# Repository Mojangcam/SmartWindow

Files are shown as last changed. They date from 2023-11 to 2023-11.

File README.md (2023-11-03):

# SmartWindow

## 사용법

* 전용 앱을 다운받아 실행 시킵니다.
* 실행을 시키면 자동으로 스마트윈도우와 연결이 됩니다.
* 왼쪽 상단에는 수동/자동 모드를 변경 할수 있는 스위치가 존재합니다.
* 오른쪽 상단에는 음성인식으로 창문을 제어할수 있게 마이크 아이콘이 존재합니다.
* 실시간으로 현재의 온도와 습도, 미세먼지의 값을 받아옵니다.
* 블루투스 연결이 자동으로 되지 않는다면 아래에 블루투스 연결 버튼을 누르면 자동으로 연결이 됩니다.
* 만약 블루투스 연결을 끊고 싶다면 바로 옆에 있는 블루투스 연결 해제 버튼을 누르면 연결이 해제 됩니다.
* 맨 아래에는 열기, 중간, 닫기의 버튼이 존재합니다.
* 열기의 버튼을 누르면 수동모드로 바뀌면서 창문이 열립니다.
* 닫기와 중간의 버튼도 누르면 수동모드로 전환되며 창문이 반만 열리거나 닫히게 됩니다.
* 앱의 사용법은 여기서 끝 입니다.

## 구성요소

### 재료

1. 미세먼지 센서
2. 온, 습도 센서
3. LCD
4. 블루투스 모듈
5. 모터 드라이버 모듈
6. DC 기어 모터
7. 브레드보드
8. 아두이노 우노
9. 리밋 스위치 2개
10. 3D프린팅한 창문

### 동작
1. 미세먼지와 온, 습도 값을 받아와 LCD에 표시해줍니다.
2. 미세먼지가 높으면 창문이 닫힙니다.
3. 미세먼지가 조금 높으면 창문이 반만 닫히거나 반만 열립니다.
4. 온도가 높아지면 창문이 열립니다.
5. 습도가 높아지면 창문이 닫힙니다.
6. 창문이 열리고 닫히는 우선순위는 닫힘 -> 반만 닫힘 -> 열림 순 입니다.

## 회로도 - 부품명 포함

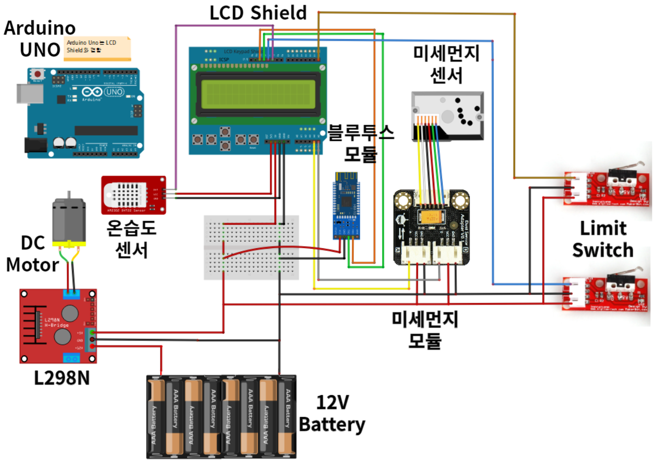
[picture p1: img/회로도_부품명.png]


## 회로도 - 부품명 미포함

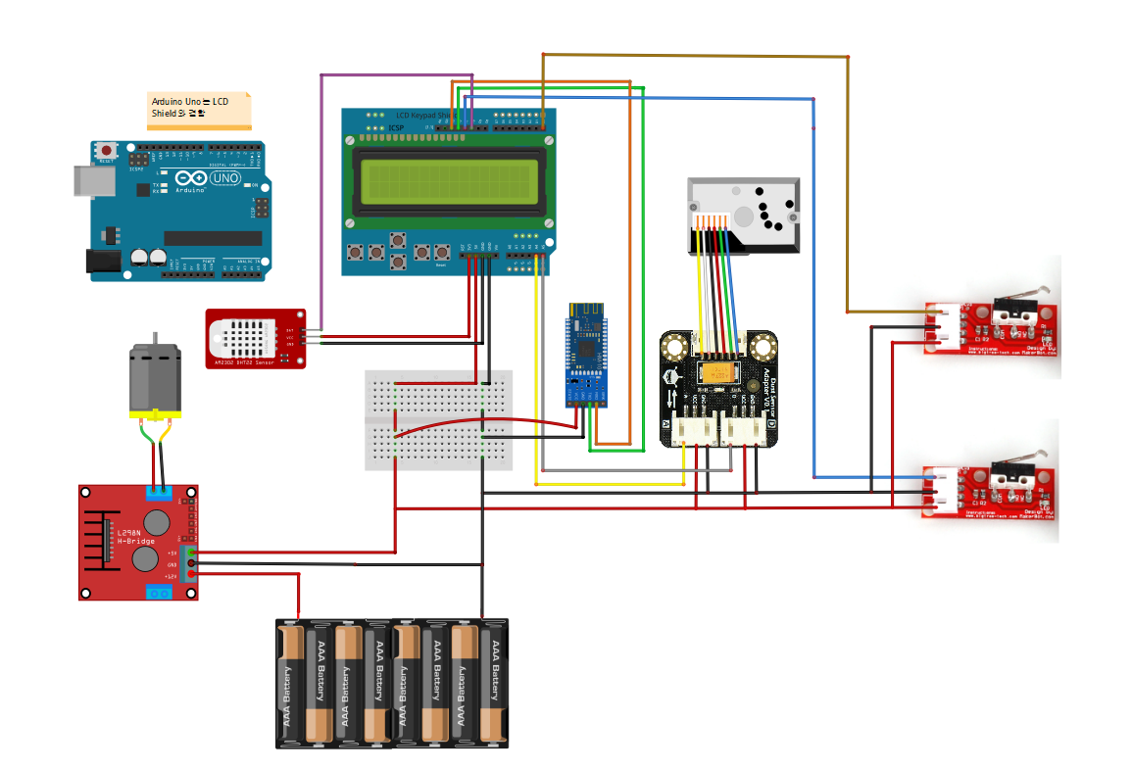
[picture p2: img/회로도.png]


## 만든 사람

### 3D 모델링 : 김수정, 조세형

### 회로 구성 : 이제현, 박상영

### 코딩 : 노종환
[동작 시연 영상 - 앱 업데이트 전](https://www.youtube.com/watch?v=2f4ua8sfkGE)

[Operation demonstration video - Before app update](https://www.youtube.com/watch?v=2f4ua8sfkGE)

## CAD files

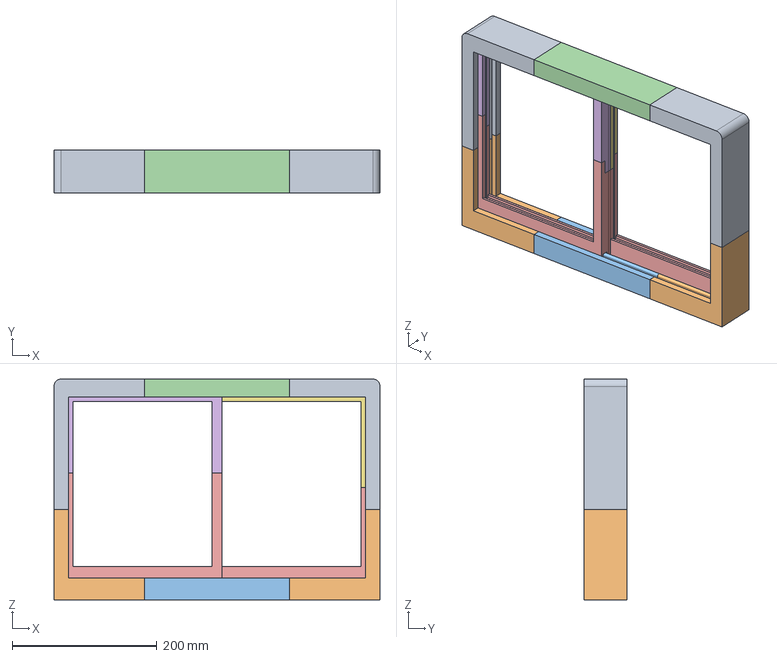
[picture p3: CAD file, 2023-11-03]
3D_Model/미니윈도.step
450.0 x 60.0 x 305.0 mm

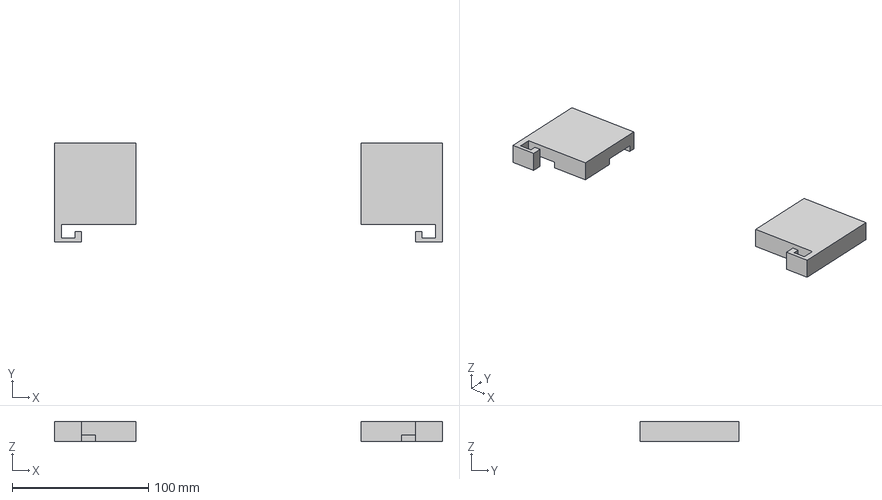
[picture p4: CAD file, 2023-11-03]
3D_Model/받침대.step
285.0 x 73.0 x 15.0 mm

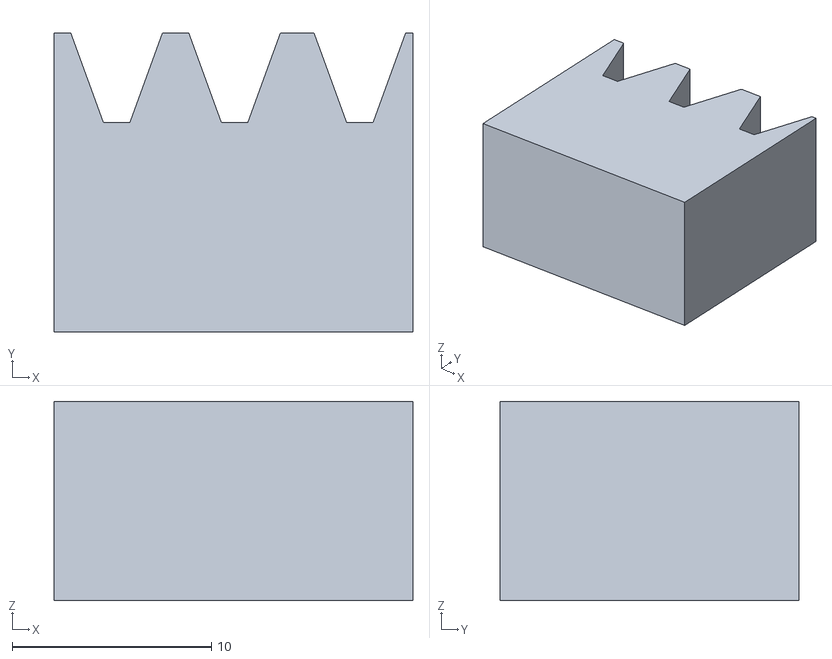
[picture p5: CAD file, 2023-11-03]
3D_Model/래크기어.stl
18.0 x 15.0 x 10.0

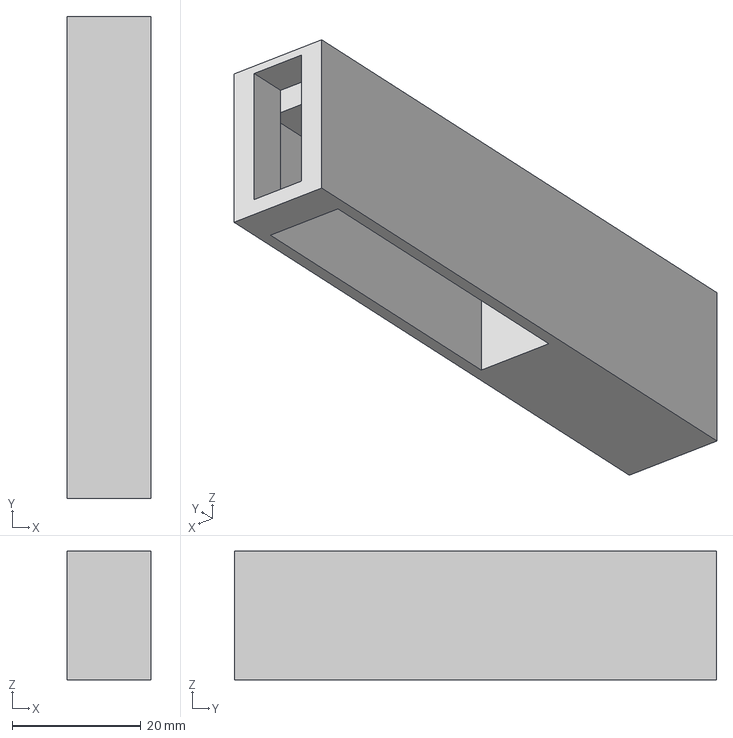
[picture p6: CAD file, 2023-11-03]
3D_Model/스위치 홈.step
13.0 x 75.0 x 20.0 mm

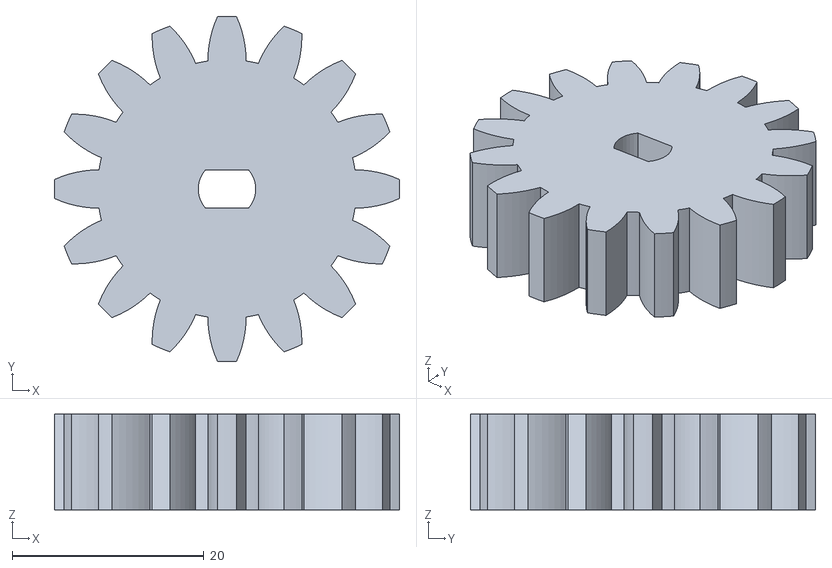
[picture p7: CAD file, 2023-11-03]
3D_Model/피니언기어.stl
36.0 x 36.0 x 10.0

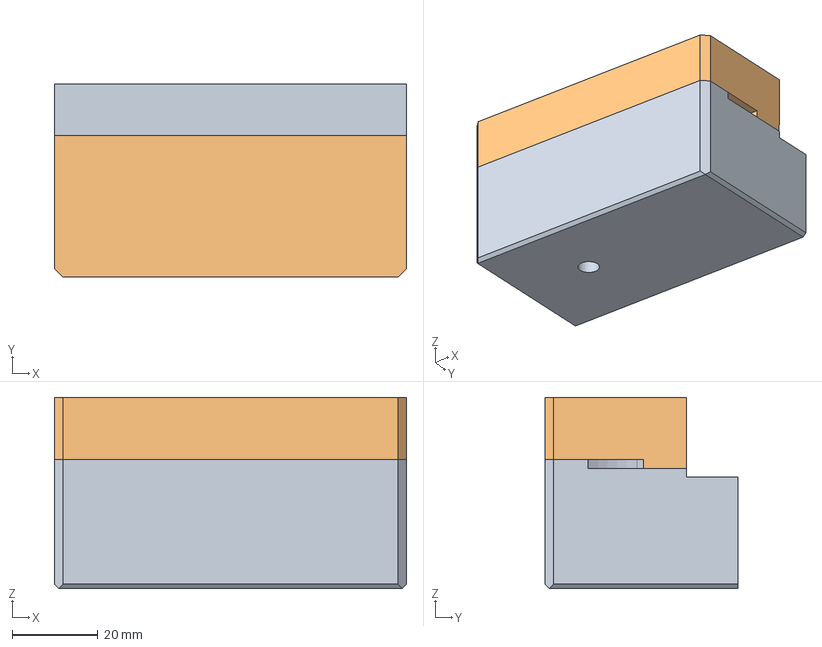
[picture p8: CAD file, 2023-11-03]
3D_Model/기어 홈.step
82.0 x 45.0 x 44.5 mm

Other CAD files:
3D_Model/기어 홈.f3d
3D_Model/래크기어.ipt
3D_Model/미니윈도.f3d
3D_Model/받침대.f3d
3D_Model/스위치 홈.f3d
3D_Model/피니언기어.ipt

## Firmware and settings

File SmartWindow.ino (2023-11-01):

#include "DHT.h"
#include <LiquidCrystal.h>
#include <SoftwareSerial.h>
#include <time.h>

#define DEFAULT_INIT_DUST 0.5
#define DHT_SENSOR_DIGITAL_PIN 10
#define DHT_SENSOR_MODEL DHT22
#define BLUETOOTH_SERIAL_RXD_PIN 12
#define BLUETOOTH_SERIAL_TXD_PIN 13

const uint8_t motor_input_pin1 = 2;
const uint8_t motor_input_pin2 = 3;
const uint8_t motor_enable_pin = 11;

LiquidCrystal lcd(8, 9, 4, 5, 6, 7);
DHT dhtSensor(DHT_SENSOR_DIGITAL_PIN,
              DHT_SENSOR_MODEL);
SoftwareSerial bluetoothSerial(BLUETOOTH_SERIAL_RXD_PIN,
                               BLUETOOTH_SERIAL_TXD_PIN);

int g_dustSensorPinNum = A4;
int g_dustSensorLedPinNum = A5;
int g_is_windowOpen = 0;
int g_is_windowClose = 0;
int g_defaultMotorPower = 100;
int g_set_automatic = 0;
int Debug = 1;

float g_dustSensorValue = 0;
float g_dustSensorVoltage = 0;
float g_dustDensity = 0;

unsigned long g_asyncStartTime;
unsigned long g_asyncEndTime;
unsigned long g_asyncStartTime2;
unsigned long g_asyncEndTime2;
unsigned long g_halfOpenMsec;

void openTheWindow();
void closeTheWindow();
void halfOpenTheWindow();
void halfOpenSetting();
void bluetoothCommand(String cmd);
void (*resetFunc)(void) = 0;
float get_dustSensorVoltage(float dustSensorValue);
float get_dustDensity(float dustSensorVoltage);
void openMotion();
void closeMotion();
void stopMotion();
bool check_bluetoothSignal();
void show_allStatus();
void serialCommand(String cmd);

void setup()
{
  Serial.begin(9600);
  bluetoothSerial.begin(9600);
  Serial.setTimeout(10);
  bluetoothSerial.setTimeout(10);
  dhtSensor.begin();
  pinMode(A1, INPUT);
  pinMode(A2, INPUT);
  pinMode(g_dustSensorLedPinNum, OUTPUT);
  pinMode(motor_input_pin1, OUTPUT);
  pinMode(motor_input_pin2, OUTPUT);
  pinMode(motor_enable_pin, OUTPUT);
  g_is_windowClose = !analogRead(A1);
  g_is_windowOpen = !analogRead(A2);
  halfOpenSetting();
  lcd.begin(16, 2);
  lcd.setCursor(0, 0);
  lcd.clear();
}

void loop()
{
  g_is_windowClose = !analogRead(A1);
  g_is_windowOpen = !analogRead(A2);
  delay(500);

  if (bluetoothSerial.available())
  {
    String data = bluetoothSerial.readString();
    Serial.println(data);
    bluetoothCommand(data);
  }
  digitalWrite(g_dustSensorLedPinNum, LOW);
  delayMicroseconds(280);
  g_dustSensorValue = analogRead(g_dustSensorPinNum);
  delayMicroseconds(40);
  digitalWrite(g_dustSensorLedPinNum, HIGH);
  delayMicroseconds(9600);
  lcd.clear();

  g_dustSensorVoltage = get_dustSensorVoltage(g_dustSensorValue);
  g_dustDensity = get_dustDensity(g_dustSensorVoltage);
  int integer_dustDensity = g_dustDensity;

  lcd.setCursor(0, 1);
  lcd.print("Dust:");
  lcd.setCursor(5, 1);
  lcd.print(integer_dustDensity);
  lcd.setCursor(8, 1);
  lcd.print("[ug/m^3]");

  float humidity = dhtSensor.readHumidity();
  float temperature = dhtSensor.readTemperature();
  float fahrenheit = dhtSensor.readTemperature(true);
  float show_lcdTemperature = dhtSensor.computeHeatIndex(temperature, humidity, false);

  lcd.setCursor(0, 0);
  lcd.print("temp:");
  lcd.setCursor(5, 0);
  lcd.print(show_lcdTemperature);
  lcd.setCursor(7, 0);
  lcd.print("C ");

  lcd.setCursor(9, 0);
  lcd.print("Hum:");
  lcd.setCursor(13, 0);
  lcd.print(humidity);
  lcd.setCursor(15, 0);
  lcd.print("%");

  if (Debug == 1 && Serial.available())
  {
    String data = Serial.readString();
    serialCommand(data);
  }

  bluetoothSerial.print((String)temperature +
                        "and" +
                        (String)humidity +
                        "and" +
                        (String)g_dustDensity);
  if (g_set_automatic)
  {
    if (humidity >= 75 ||
        g_dustDensity > 600)
    {
      closeTheWindow();
    }
    else if (temperature >= 30)
    {
      openTheWindow();
    }
    else if (g_dustDensity >= 100 &&
             g_dustDensity <= 300)
    {
      halfOpenTheWindow();
    }
  }
}

float get_dustSensorVoltage(float dustSensorValue)
{
  float returnValue = dustSensorValue * 5.0 / 1024;
  return returnValue;
}

float get_dustDensity(float dustSensorVoltage)
{
  float returnValue = (dustSensorVoltage -
                       DEFAULT_INIT_DUST) /
                      0.005;
  return returnValue;
}

void openTheWindow()
{
  g_is_windowOpen = !analogRead(A2);
  if (g_is_windowOpen)
  {
    stopMotion();
  }
  else
  {
    g_asyncStartTime = millis();
    openMotion();

    while (1)
    {
      g_is_windowOpen = !analogRead(A2);
      g_asyncEndTime = millis();
      if (g_asyncEndTime - g_asyncStartTime > 2000)
      {
        stopMotion();
        break;
      }
      else
      {
        if (g_is_windowOpen)
        {
          g_asyncStartTime2 = millis();
          while (1)
          {
            g_is_windowOpen = !analogRead(A2);
            g_asyncEndTime2 = millis();
            if (g_asyncEndTime2 - g_asyncStartTime2 > 500 &&
                g_is_windowOpen)
            {
              stopMotion();
              break;
            }
          }
          break;
        }
        if (bluetoothSerial.available()){
          stopMotion();
          bluetoothCommand(bluetoothSerial.readString());
          break;
        }
      }
    }
  }
}

void closeTheWindow()
{
  g_is_windowClose = !analogRead(A1);
  if (g_is_windowClose)
  {
    stopMotion();
  }
  else
  {
    g_asyncStartTime = millis();
    closeMotion();

    while (1)
    {
      g_is_windowClose = !analogRead(A1);
      g_asyncEndTime = millis();
      if (g_asyncEndTime - g_asyncStartTime > 2000)
      {
        stopMotion();
        break;
      }
      else
      {
        if (g_is_windowClose)
        {
          g_asyncStartTime2 = millis();
          while (1)
          {
            g_is_windowClose = !analogRead(A1);
            g_asyncEndTime2 = millis();
            if (g_asyncEndTime2 - g_asyncStartTime2 > 500 &&
                g_is_windowClose)
            {
              stopMotion();
              break;
            }
          }
          break;
        }
        if (bluetoothSerial.available()){
          stopMotion();
          bluetoothCommand(bluetoothSerial.readString());
          break;
        }
      }
    }
  }
}

void halfOpenTheWindow()
{
  if (!g_is_windowClose && !g_is_windowOpen)
  {
    stopMotion();
  }
  else
  {
    if (g_is_windowClose)
    {
      g_asyncStartTime = millis();
      openMotion();
      while (1)
      {
        g_asyncEndTime = millis();
        if (g_asyncEndTime - g_asyncStartTime > g_halfOpenMsec)
        {
          stopMotion();
          break;
        }
        else if (bluetoothSerial.available()){
          stopMotion();
          bluetoothCommand(bluetoothSerial.readString());
          break;
        }
      }
    }
    if (g_is_windowOpen)
    {
      g_asyncStartTime = millis();
      closeMotion();
      while (1)
      {
        g_asyncEndTime = millis();
        if (g_asyncEndTime - g_asyncStartTime > g_halfOpenMsec)
        {
          stopMotion();
          break;
        }
        else if (bluetoothSerial.available()){
          stopMotion();
          bluetoothCommand(bluetoothSerial.readString());
          break;
        }
      }
    }
  }
}

void bluetoothCommand(String cmd)
{
  if (cmd == "open")
  {
    g_set_automatic = 0;
    openTheWindow();
  }
  else if (cmd == "close")
  {
    g_set_automatic = 0;
    closeTheWindow();
  }
  else if (cmd == "half")
  {
    g_set_automatic = 0;
    halfOpenTheWindow();
  }
  else if (cmd == "automatic")
  {
    g_set_automatic = 1;
  }

  else if (cmd == "passive")
  {
    g_set_automatic = 0;
  }

  else if (cmd == "반만 열어 줘 참깨" ||
           cmd == "반만 열어 줘" ||
           cmd == "창문 반만 열어 줘" ||
           cmd == "창문 반만 닫아 줘" ||
           cmd == "반만 닫아 줘")
  {
    halfOpenTheWindow();
  }

  else if (cmd == "열려라 참깨" ||
           cmd == "창문 열어 줘" ||
           cmd == "열어 줘")
  {
    openTheWindow();
  }
  else if (cmd == "닫혀라 참깨" ||
           cmd == "다쳐라 참깨" ||
           cmd == "창문 닫아 줘" ||
           cmd == "닫아 줘")
  {
    closeTheWindow();
  }
}

void halfOpenSetting()
{
  unsigned long startTime, endTime;
  int num1_setting = 0;
  int num2_setting = 0;
  g_is_windowClose = !analogRead(A1);
  g_is_windowOpen = !analogRead(A2);
  if (g_is_windowOpen ||
      !g_is_windowOpen && !g_is_windowClose){
    closeMotion();
    startTime = millis();
    while(1){
      endTime = millis();
      if (endTime - startTime > 5000 &&
          !g_is_windowClose){
        stopMotion();
        break;
      }
      else{
        g_is_windowClose = !analogRead(A1);
        g_is_windowOpen = !analogRead(A2);
        if (g_is_windowClose){
          num1_setting = 1;
          break;
        }
      }
    }
  }
  if(g_is_windowClose && num1_setting){
    g_asyncStartTime = millis();
    startTime = millis();
    openMotion();
    while(1){
      endTime = millis();
      if (endTime - startTime > 5000){
        stopMotion();
        break;
      }
      else{
        g_is_windowClose = !analogRead(A1);
        g_is_windowOpen = !analogRead(A2);
        if (g_is_windowOpen){
          g_asyncEndTime = millis();
          g_halfOpenMsec = (g_asyncEndTime - g_asyncStartTime) / 2;
          delay(200);
          stopMotion();
          break;
        }
      }
    }
  }
  if(g_is_windowClose &&
    !num1_setting &&
    !num2_setting){
      g_asyncStartTime = millis();
      startTime = millis();
      openMotion();
      while(1){
        endTime = millis();
        if(endTime - startTime > 5000){
          stopMotion();
          break;
        }
        else{
          g_is_windowClose = !analogRead(A1);
          g_is_windowOpen = !analogRead(A2);
          if (g_is_windowOpen){
            g_asyncEndTime = millis();
            g_halfOpenMsec = (g_asyncEndTime - g_asyncStartTime) / 2;
            delay(200);
            stopMotion();
            break;

          }
        }
      }
    }
}

void openMotion()
{
  digitalWrite(motor_input_pin1, HIGH);
  digitalWrite(motor_input_pin2, LOW);
  analogWrite(motor_enable_pin,
              g_defaultMotorPower);
}

void closeMotion()
{
  digitalWrite(motor_input_pin1, LOW);
  digitalWrite(motor_input_pin2, HIGH);
  analogWrite(motor_enable_pin,
              g_defaultMotorPower);
}

void stopMotion()
{
  digitalWrite(motor_input_pin1, LOW);
  digitalWrite(motor_input_pin2, LOW);
  analogWrite(motor_enable_pin, 0);
}

bool check_bluetoothSignal()
{
  if (bluetoothSerial.available())
  {
    String data = bluetoothSerial.readString();
    if (data)
    {
      bluetoothCommand(data);
      return true;
    }
    else
    {
      return false;
    }
  }
  else
  {
    return false;
  }
}

void serialCommand(String cmd)
{
}

void show_allStatus()
{
  Serial.println("Debug Start!");
  Serial.println("Input Variable Name");
}
